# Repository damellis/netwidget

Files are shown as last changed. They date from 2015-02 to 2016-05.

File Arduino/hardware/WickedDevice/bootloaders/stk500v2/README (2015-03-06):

make clean

make goldilocks
OR
make goldilocks_22

make program

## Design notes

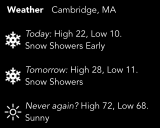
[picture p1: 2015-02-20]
Arduino/spitftbitmap/weather2.bmp

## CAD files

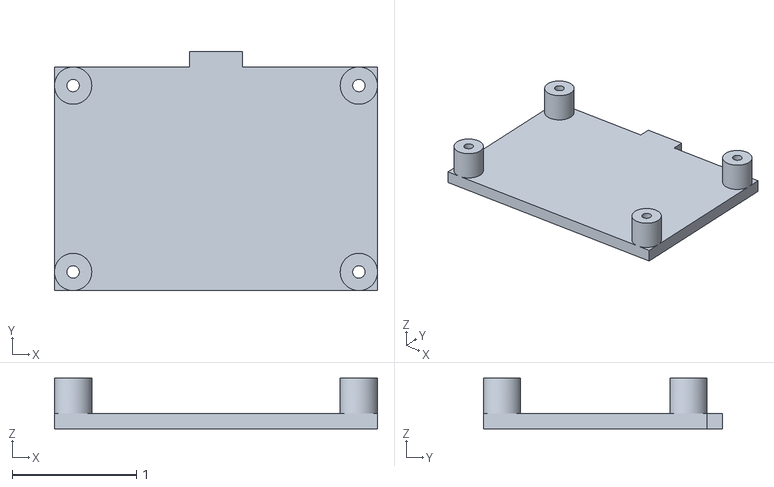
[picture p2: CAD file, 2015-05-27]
Rhino/Enclosure Bottom.stl
2.60 x 1.92 x 0.41

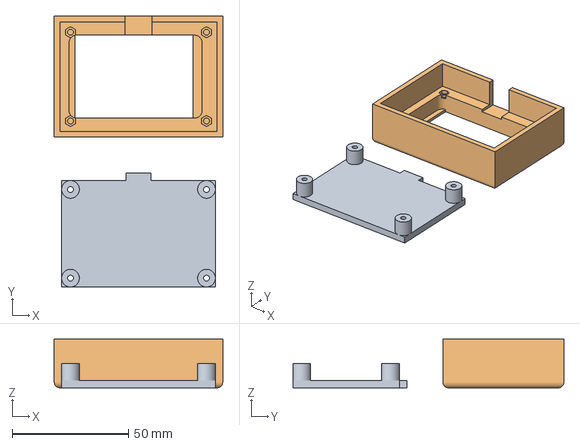
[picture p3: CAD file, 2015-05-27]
Rhino/Enclosure.amf
72.4 x 116.4 x 21.0 mm

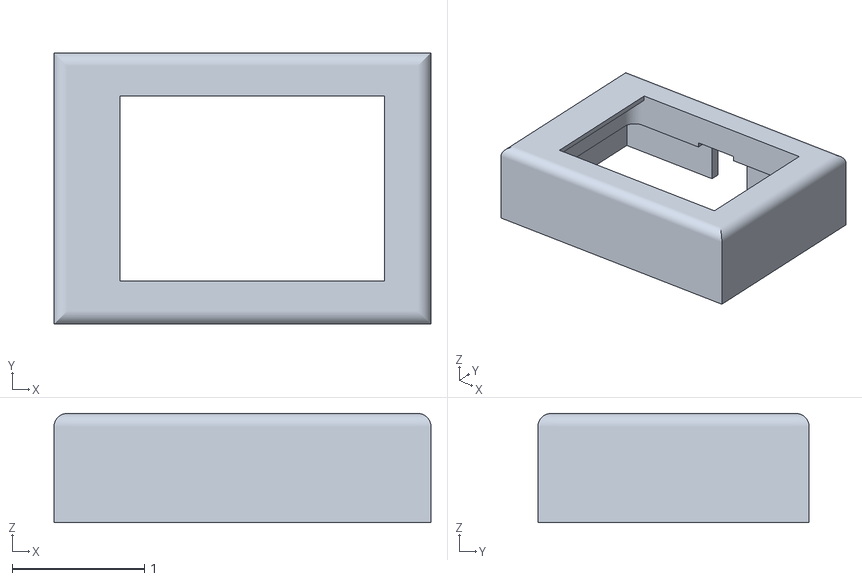
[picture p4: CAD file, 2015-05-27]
Rhino/Enclosure Top.stl
2.85 x 2.05 x 0.825

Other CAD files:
Rhino/Enclosure.3dm

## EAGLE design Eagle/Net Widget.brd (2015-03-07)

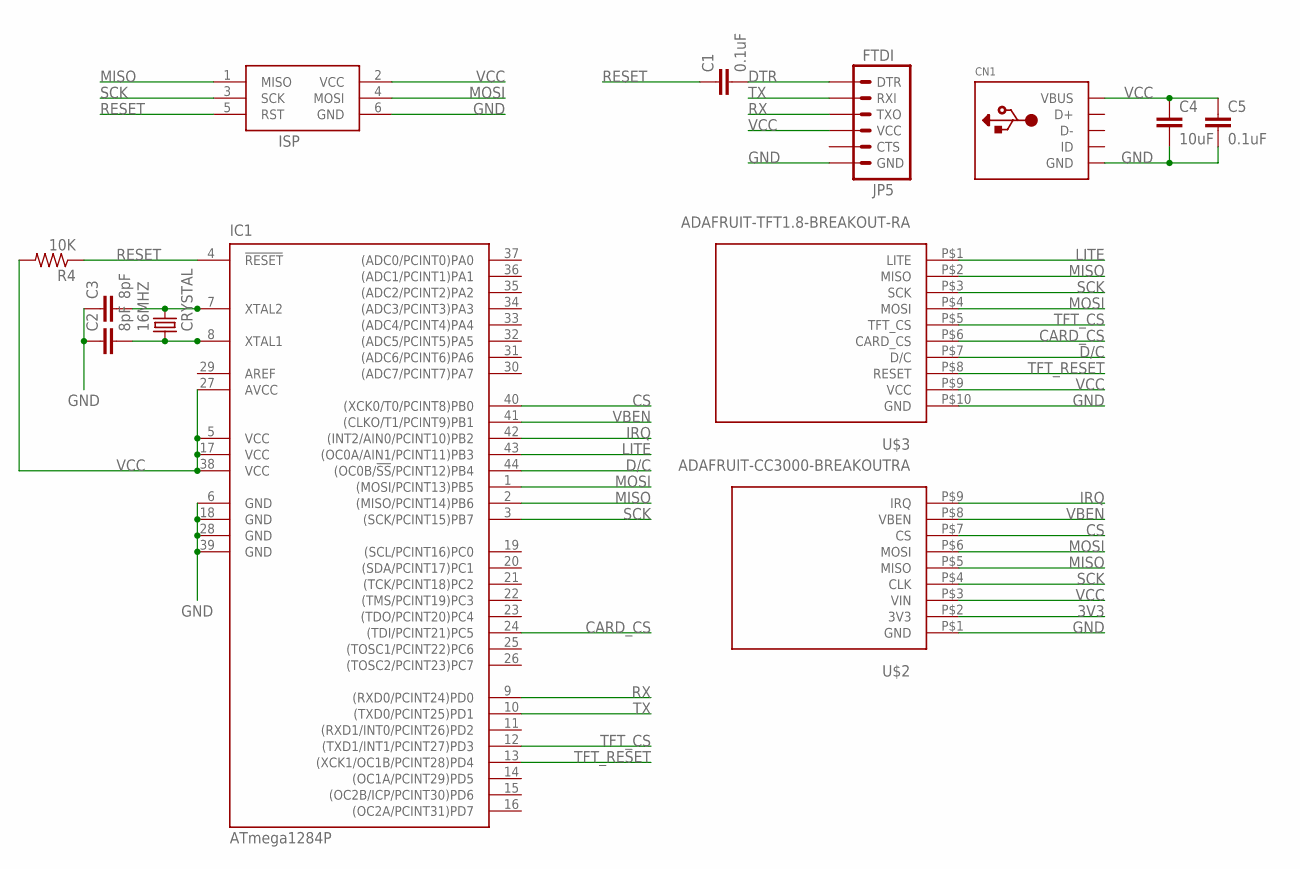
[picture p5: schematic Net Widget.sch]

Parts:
16MHZ: CRYSTAL; 2-SMD-5X3MM
C1, C5: 0.1uF; C1206
C2, C3: 8pF; C1206
C4: 10uF; C1206
CN1: USBPWR; USB-MINIB-POWER
IC1: ATmega1284P; TQFP44
ISP: AVRISP-6; AVRISP
JP5: FTDI; 1X06-SMD
R4: 10K; R1206
U$2: ADAFRUIT-CC3000-BREAKOUTRA; ADAFRUIT-CC3000-BREAKOUT-RA
U$3: ADAFRUIT-TFT1.8-BREAKOUT-RA

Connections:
3V3: U$2.P$2 (3V3)
AREF: IC1.29 (AREF)
CARD_CS: IC1.24 ((TDI/PCINT21)PC5), U$3.P$6 (CARD_CS)
CS: IC1.40 ((XCK0/T0/PCINT8)PB0), U$2.P$7 (CS)
D/C: IC1.44 ((OC0B/!SS!/PCINT12)PB4), U$3.P$7 (D/C)
DTR: C1.2, JP5.1 (DTR)
GND: C2.1, C3.1, C4.2, C5.2, CN1.GND, IC1.6 (GND), IC1.18 (GND), IC1.28 (GND), IC1.39 (GND), ISP.6 (GND), JP5.6 (GND), U$2.P$1 (GND), U$3.P$10 (GND)
IRQ: IC1.42 ((INT2/AIN0/PCINT10)PB2), U$2.P$9 (IRQ)
LITE: IC1.43 ((OC0A/AIN1/PCINT11)PB3), U$3.P$1 (LITE)
MISO: IC1.2 ((MISO/PCINT14)PB6), ISP.1 (MISO), U$2.P$5 (MISO), U$3.P$2 (MISO)
MOSI: IC1.1 ((MOSI/PCINT13)PB5), ISP.4 (MOSI), U$2.P$6 (MOSI), U$3.P$4 (MOSI)
unnamed: 16MHZ.P$2 (2), C3.2, IC1.7 (XTAL2)
unnamed: 16MHZ.P$1 (1), C2.2, IC1.8 (XTAL1)
RESET: C1.1, IC1.4 (!RESET), ISP.5 (RST), R4.1
RX: IC1.9 ((RXD0/PCINT24)PD0), JP5.3 (TXO)
SCK: IC1.3 ((SCK/PCINT15)PB7), ISP.3 (SCK), U$2.P$4 (CLK), U$3.P$3 (SCK)
TFT_CS: IC1.12 ((TXD1/INT1/PCINT27)PD3), U$3.P$5 (TFT_CS)
TFT_RESET: IC1.13 ((XCK1/OC1B/PCINT28)PD4), U$3.P$8 (RESET)
TX: IC1.10 ((TXD0/PCINT25)PD1), JP5.2 (RXI)
VBEN: IC1.41 ((CLKO/T1/PCINT9)PB1), U$2.P$8 (VBEN)
VCC: C4.1, C5.1, CN1.VBUS, IC1.5 (VCC), IC1.17 (VCC), IC1.27 (AVCC), IC1.38 (VCC), ISP.2 (VCC), JP5.4 (VCC), R4.2, U$2.P$3 (VIN), U$3.P$9 (VCC)

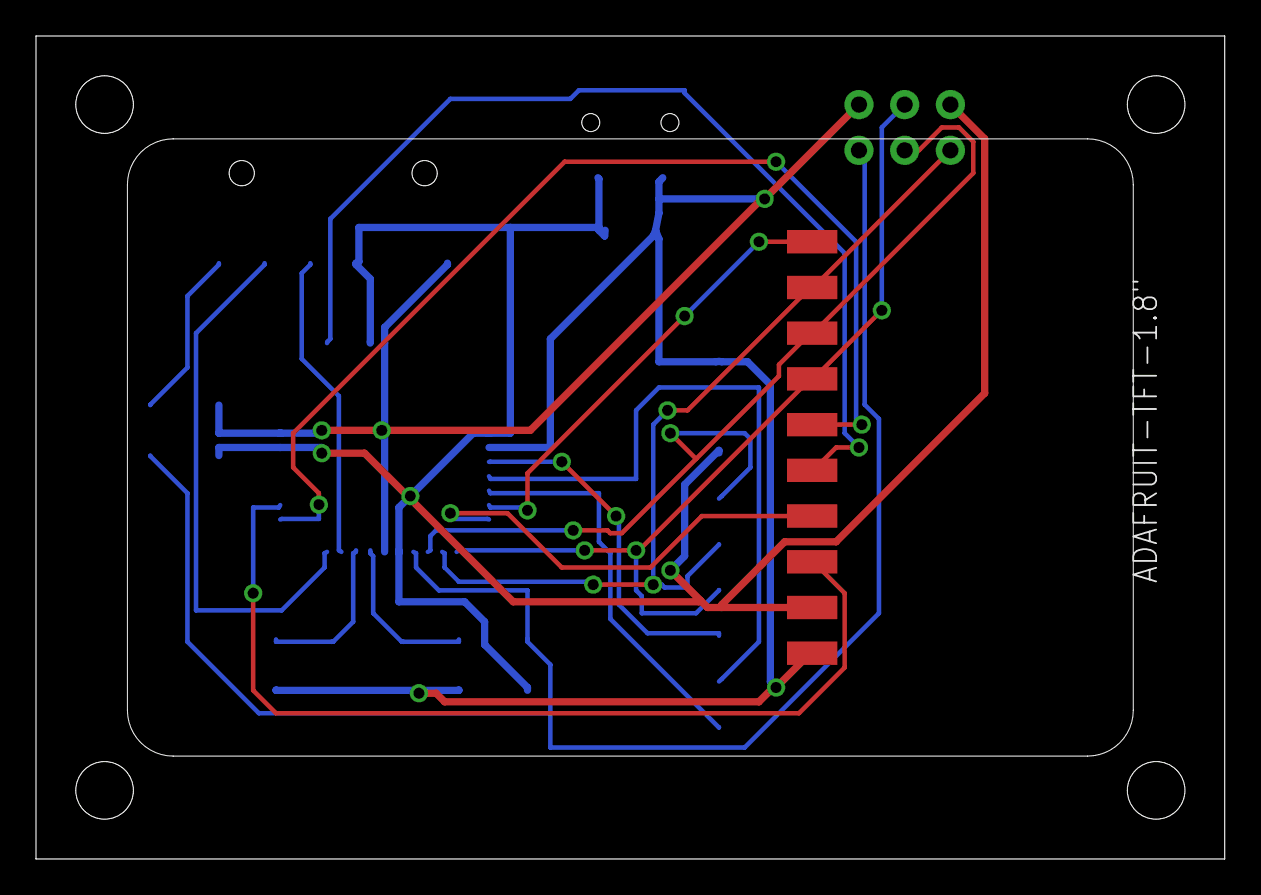
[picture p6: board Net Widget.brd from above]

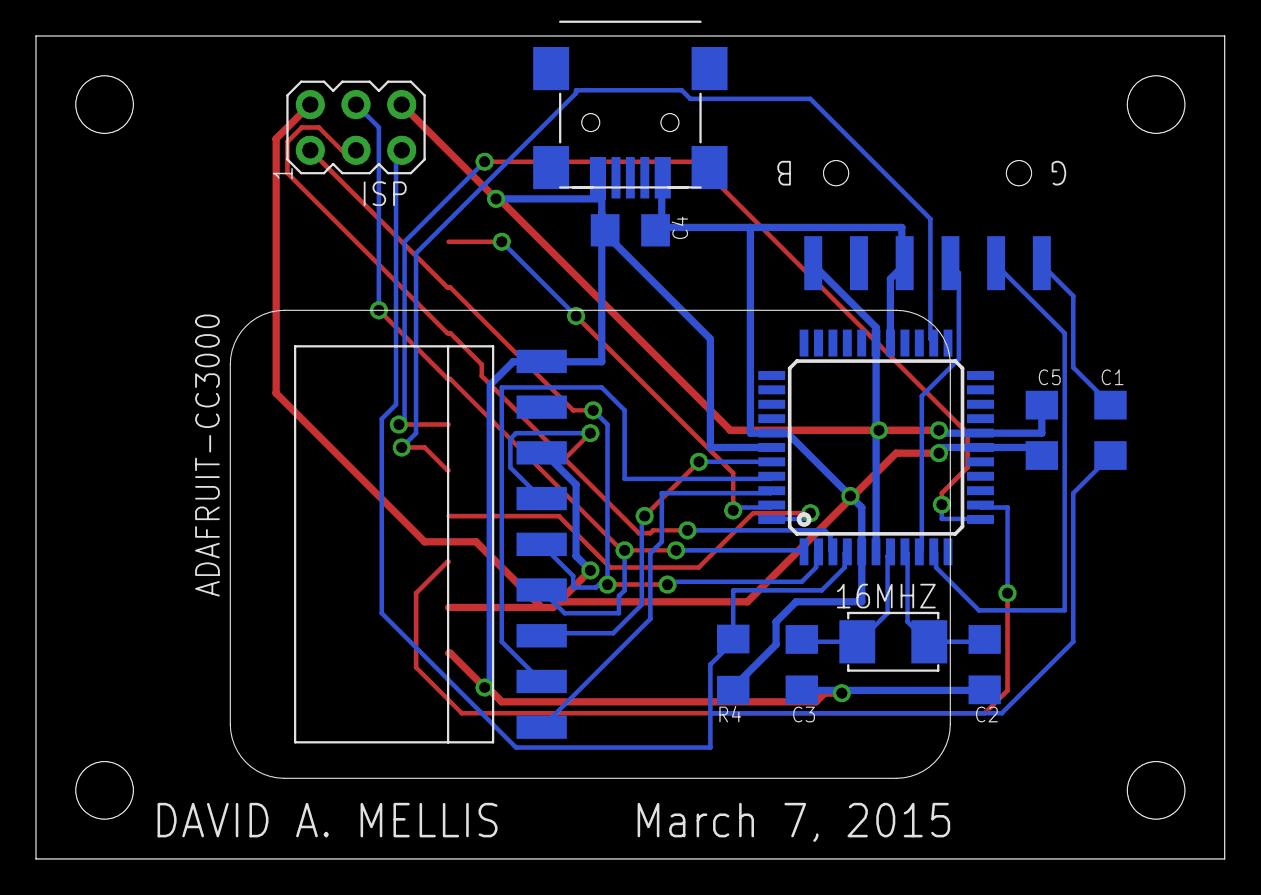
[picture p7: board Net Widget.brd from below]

Board: 2 copper layers, 66.0 x 45.7 mm, 13 parts (12 on the bottom side), 19 nets.

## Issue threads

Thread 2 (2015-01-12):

Make holes for breakout boards bigger.

damellis, 2015-01-12:

damellis, 2015-02-05:
Fixed in 80cd00d5e71479a2df2b87086648b5eec6168d64

Closed 2015-02-05.

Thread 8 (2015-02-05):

Determine correct resistor values for RGB LED.

damellis, 2015-02-05:

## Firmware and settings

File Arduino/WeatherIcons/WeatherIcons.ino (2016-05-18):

// Images from: https://thenounproject.com/DmitryBaranovskiy/collection/weatheroo/

#include <SD.h>
#include <SPI.h>
#include <Temboo.h>
#include <TFT.h>
#include <Adafruit_CC3000.h>

#include "Conditions.h"
#include "TembooAccount.h"

Adafruit_CC3000 cc3000(21, 22, 23); // CS, IRQ, VBEN
Adafruit_CC3000_Client client;
TFT tft(3, 9, 8); // CS, DC, Reset
unsigned long ip;
boolean sd;

void setup() {
  Serial.begin(9600);
  
  if(SD.begin(16)) {
    sd = true;
    for (int i = 0; i < NUM_IMAGES; i++) {
      images[i] = tft.loadImage(filenames[i]);
    }
  } else {
    sd = false;
    tft.println("SD init failed.");
    Serial.println("SD init failed.");
  }

  // TFT backlight  
  pinMode(4, OUTPUT);
  digitalWrite(4, HIGH);
  
  tft.begin();
  tft.setRotation(3);
  tft.background(0, 0, 0);
  tft.setCursor(0, 0);
  tft.stroke(255, 255, 255);
  tft.setTextWrap(true);
  
  tft.println(F("Hello."));
  Serial.println(F("Hello."));
  
  tft.println(F("Initializing CC3000..."));
  Serial.println(F("Initializing CC3000..."));

  if (!cc3000.begin()) {
    tft.println(F("cc3000.begin() failed."));
    Serial.println(F("cc3000.begin() failed."));
    while (1);
  }
  
  tft.print(F("Connecting to ")); tft.print(WIFI_SSID); tft.println(F("..."));
  Serial.print(F("Connecting to ")); Serial.print(WIFI_SSID); Serial.println(F("..."));
  
  while (!cc3000.connectToAP(WIFI_SSID, WIFI_PASS, WIFI_SEC)) {
    tft.println(F("Connection failed. Retrying in 10 seconds."));
    Serial.println(F("Connection failed. Retrying in 10 seconds."));
    delay(10000);
  }
  
  tft.print(F("Getting IP addresss..."));
  Serial.print(F("Getting IP addresss..."));
  while(!cc3000.checkDHCP()) {
    tft.print(".");
    Serial.print(".");
    delay(100);
  }
  tft.println();
  Serial.println();
  
  /* Display the IP address DNS, Gateway, etc. */  
  while (!displayConnectionDetails()) {
    delay(1000);
  }
  
  tft.println(F("Connected."));
  Serial.println(F("Connected"));
}


void loop() {
  Serial.print(F("Running GetWeatherByAddress..."));

  TembooChoreo GetWeatherByAddressChoreo(client);

  // Invoke the Temboo client
  GetWeatherByAddressChoreo.begin();

  // Set Temboo account credentials
  GetWeatherByAddressChoreo.setAccountName(TEMBOO_ACCOUNT);
  GetWeatherByAddressChoreo.setAppKeyName(TEMBOO_APP_KEY_NAME);
  GetWeatherByAddressChoreo.setAppKey(TEMBOO_APP_KEY);

  // Set Choreo inputs
  String AddressValue = "Berkeley, CA";
  GetWeatherByAddressChoreo.addInput("Address", AddressValue);
  
  // Filter Choreo output
  GetWeatherByAddressChoreo.addOutputFilter("code", "/rss/channel/item/yweather:condition/@code", "Response");  
  GetWeatherByAddressChoreo.addOutputFilter("date", "/rss/channel/item/yweather:condition/@date", "Response");
  GetWeatherByAddressChoreo.addOutputFilter("temp", "/rss/channel/item/yweather:condition/@temp", "Response");
  GetWeatherByAddressChoreo.addOutputFilter("text", "/rss/channel/item/yweather:condition/@text", "Response");
  GetWeatherByAddressChoreo.addOutputFilter("date1", "/rss/channel/item/yweather:forecast[1]/@date", "Response");
  GetWeatherByAddressChoreo.addOutputFilter("low1", "/rss/channel/item/yweather:forecast[1]/@low", "Response");
  GetWeatherByAddressChoreo.addOutputFilter("high1", "/rss/channel/item/yweather:forecast[1]/@high", "Response");
  GetWeatherByAddressChoreo.addOutputFilter("text1", "/rss/channel/item/yweather:forecast[1]/@text", "Response");
  GetWeatherByAddressChoreo.addOutputFilter("date2", "/rss/channel/item/yweather:forecast[2]/@date", "Response");
  GetWeatherByAddressChoreo.addOutputFilter("low2", "/rss/channel/item/yweather:forecast[2]/@low", "Response");
  GetWeatherByAddressChoreo.addOutputFilter("high2", "/rss/channel/item/yweather:forecast[2]/@high", "Response");
  GetWeatherByAddressChoreo.addOutputFilter("text2", "/rss/channel/item/yweather:forecast[2]/@text", "Response");

  // Identify the Choreo to run
  GetWeatherByAddressChoreo.setChoreo("/Library/Yahoo/Weather/GetWeatherByAddress");
  
  // Run the Choreo; when results are available, print them to serial
  GetWeatherByAddressChoreo.run();
  
  Serial.println("done.");
  
  String date, temp, text, date1, low1, high1, text1, date2, low2, high2, text2, http_code;
  int code;
  
  Serial.println(F("Retrieving results..."));

  while (GetWeatherByAddressChoreo.available()) {
    String key = GetWeatherByAddressChoreo.readStringUntil('\x1F');
    String value = GetWeatherByAddressChoreo.readStringUntil('\x1E');
    
    key.trim(); value.trim();
    
    Serial.print(key);
    Serial.print("\t");
    Serial.print(value);
    Serial.println();
    
    if (key == "code") code = value.toInt();
    if (key == "date") date = value;
    if (key == "temp") temp = value;
    if (key == "text") text = value;
    if (key == "date1") date1 = value;
    if (key == "low1") low1 = value;
    if (key == "high1") high1 = value;
    if (key == "text1") text1 = value;
    if (key == "date2") date2 = value;
    if (key == "low2") low2 = value;
    if (key == "high2") high2 = value;
    if (key == "text2") text2 = value;
    if (key == "HTTP_CODE") http_code = value;
  }
  GetWeatherByAddressChoreo.close();

  // if successful, print the new forecast.
  if (http_code.equals("200")) {
    Serial.println("Success!");
    tft.background(0, 0, 0); // clear screen
    tft.setCursor(0, 0);
    tft.stroke(255, 255, 255);
    tft.setTextWrap(true);
    tft.setTextSize(3);
    tft.println(temp);
    tft.setTextSize(1);
    tft.println(text);
    tft.println();
    tft.println();
    tft.print("Today: "); tft.print(low1); tft.print("-"); tft.print(high1); tft.print(" F"); tft.println();
    tft.println(text1);
    tft.println();
    tft.print("Tomorrow: "); tft.print(low2); tft.print("-"); tft.print(high2); tft.print(" F"); tft.println();
    tft.println(text2);
    tft.setCursor(0, 108);
    tft.println(AddressValue);
    tft.println(date.substring(0, date.lastIndexOf(" "))); // remove timezone
    if (sd && conditions[code] != -1) tft.image(images[conditions[code]], 110, 0);
    Serial.println("Done.");
    delay(1L * 60 * 60 * 1000); // on success, wait one hour
  } else {
//    tft.setCursor(0, 100);
//    tft.print(http_code);
    delay(30L * 1000); // otherwise, wait 30 seconds
  }
}

bool displayConnectionDetails(void)
{
  uint32_t ipAddress, netmask, gateway, dhcpserv, dnsserv;
  
  if(!cc3000.getIPAddress(&ipAddress, &netmask, &gateway, &dhcpserv, &dnsserv))
  {
    Serial.println(F("Unable to retrieve the IP Address!\r\n"));
    return false;
  }
  else
  {
    Serial.print(F("\nIP Addr: ")); cc3000.printIPdotsRev(ipAddress);
    Serial.print(F("\nNetmask: ")); cc3000.printIPdotsRev(netmask);
    Serial.print(F("\nGateway: ")); cc3000.printIPdotsRev(gateway);
    Serial.print(F("\nDHCPsrv: ")); cc3000.printIPdotsRev(dhcpserv);
    Serial.print(F("\nDNSserv: ")); cc3000.printIPdotsRev(dnsserv);
    Serial.println();
    return true;
  }
}

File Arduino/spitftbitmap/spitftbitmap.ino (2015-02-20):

/***************************************************
  This is a library for the Adafruit 1.8" SPI display.

This library works with the Adafruit 1.8" TFT Breakout w/SD card
  ----> http://www.adafruit.com/products/358
The 1.8" TFT shield
  ----> https://www.adafruit.com/product/802
The 1.44" TFT breakout
  ----> https://www.adafruit.com/product/2088
as well as Adafruit raw 1.8" TFT display
  ----> http://www.adafruit.com/products/618

  Check out the links above for our tutorials and wiring diagrams
  These displays use SPI to communicate, 4 or 5 pins are required to
  interface (RST is optional)
  Adafruit invests time and resources providing this open source code,
  please support Adafruit and open-source hardware by purchasing
  products from Adafruit!

  Written by Limor Fried/Ladyada for Adafruit Industries.
  MIT license, all text above must be included in any redistribution
 ****************************************************/

#include <Adafruit_GFX.h>    // Core graphics library
#include <Adafruit_ST7735.h> // Hardware-specific library
#include <SPI.h>
#include <SD.h>

// TFT display and SD card will share the hardware SPI interface.
// Hardware SPI pins are specific to the Arduino board type and
// cannot be remapped to alternate pins.  For Arduino Uno,
// Duemilanove, etc., pin 11 = MOSI, pin 12 = MISO, pin 13 = SCK.
#define TFT_CS   0  // Chip select line for TFT display
#define TFT_RST  1  // Reset line for TFT (or see below...)
#define TFT_DC   4  // Data/command line for TFT

#define SD_CS   18  // Chip select line for SD card

//Use this reset pin for the shield!
//#define TFT_RST  0  // you can also connect this to the Arduino reset!

Adafruit_ST7735 tft = Adafruit_ST7735(TFT_CS, TFT_DC, TFT_RST);

void setup(void) {
  Serial.begin(9600);

  // TFT backlight  
  pinMode(3, OUTPUT);
  digitalWrite(3, HIGH);

  // Use this initializer if you're using a 1.8" TFT
  tft.initR(INITR_BLACKTAB);

  // Use this initializer (uncomment) if you're using a 1.44" TFT
  //tft.initR(INITR_144GREENTAB);
  
  tft.setRotation(3);

  Serial.print("Initializing SD card...");
  if (!SD.begin(SD_CS)) {
    Serial.println("failed!");
    return;
  }
  Serial.println("OK!");

  // change the name here!
  bmpDraw("weather2.bmp", 0, 0);
  // wait 5 seconds
  delay(5000);
}

void loop() {
// uncomment these lines to draw bitmaps in different locations/rotations!
/*
  tft.fillScreen(ST7735_BLACK); // Clear display
  for(uint8_t i=0; i<4; i++)    // Draw 4 parrots
    bmpDraw("parrot.bmp", tft.width() / 4 * i, tft.height() / 4 * i);
  delay(1000);
  tft.setRotation(tft.getRotation() + 1); // Inc rotation 90 degrees
*/
}

// This function opens a Windows Bitmap (BMP) file and
// displays it at the given coordinates.  It's sped up
// by reading many pixels worth of data at a time
// (rather than pixel by pixel).  Increasing the buffer
// size takes more of the Arduino's precious RAM but
// makes loading a little faster.  20 pixels seems a
// good balance.

#define BUFFPIXEL 20

void bmpDraw(char *filename, uint8_t x, uint8_t y) {

  File     bmpFile;
  int      bmpWidth, bmpHeight;   // W+H in pixels
  uint8_t  bmpDepth;              // Bit depth (currently must be 24)
  uint32_t bmpImageoffset;        // Start of image data in file
  uint32_t rowSize;               // Not always = bmpWidth; may have padding
  uint8_t  sdbuffer[3*BUFFPIXEL]; // pixel buffer (R+G+B per pixel)
  uint8_t  buffidx = sizeof(sdbuffer); // Current position in sdbuffer
  boolean  goodBmp = false;       // Set to true on valid header parse
  boolean  flip    = true;        // BMP is stored bottom-to-top
  int      w, h, row, col;
  uint8_t  r, g, b;
  uint32_t pos = 0, startTime = millis();

  if((x >= tft.width()) || (y >= tft.height())) return;

  Serial.println();
  Serial.print("Loading image '");
  Serial.print(filename);
  Serial.println('\'');

  // Open requested file on SD card
  if ((bmpFile = SD.open(filename)) == NULL) {
    Serial.print("File not found");
    return;
  }

  // Parse BMP header
  if(read16(bmpFile) == 0x4D42) { // BMP signature
    Serial.print("File size: "); Serial.println(read32(bmpFile));
    (void)read32(bmpFile); // Read & ignore creator bytes
    bmpImageoffset = read32(bmpFile); // Start of image data
    Serial.print("Image Offset: "); Serial.println(bmpImageoffset, DEC);
    // Read DIB header
    Serial.print("Header size: "); Serial.println(read32(bmpFile));
    bmpWidth  = read32(bmpFile);
    bmpHeight = read32(bmpFile);
    if(read16(bmpFile) == 1) { // # planes -- must be '1'
      bmpDepth = read16(bmpFile); // bits per pixel
      Serial.print("Bit Depth: "); Serial.println(bmpDepth);
      if((bmpDepth == 24) && (read32(bmpFile) == 0)) { // 0 = uncompressed

        goodBmp = true; // Supported BMP format -- proceed!
        Serial.print("Image size: ");
        Serial.print(bmpWidth);
        Serial.print('x');
        Serial.println(bmpHeight);

        // BMP rows are padded (if needed) to 4-byte boundary
        rowSize = (bmpWidth * 3 + 3) & ~3;

        // If bmpHeight is negative, image is in top-down order.
        // This is not canon but has been observed in the wild.
        if(bmpHeight < 0) {
          bmpHeight = -bmpHeight;
          flip      = false;
        }

        // Crop area to be loaded
        w = bmpWidth;
        h = bmpHeight;
        if((x+w-1) >= tft.width())  w = tft.width()  - x;
        if((y+h-1) >= tft.height()) h = tft.height() - y;

        // Set TFT address window to clipped image bounds
        tft.setAddrWindow(x, y, x+w-1, y+h-1);

        for (row=0; row<h; row++) { // For each scanline...

          // Seek to start of scan line.  It might seem labor-
          // intensive to be doing this on every line, but this
          // method covers a lot of gritty details like cropping
          // and scanline padding.  Also, the seek only takes
          // place if the file position actually needs to change
          // (avoids a lot of cluster math in SD library).
          if(flip) // Bitmap is stored bottom-to-top order (normal BMP)
            pos = bmpImageoffset + (bmpHeight - 1 - row) * rowSize;
          else     // Bitmap is stored top-to-bottom
            pos = bmpImageoffset + row * rowSize;
          if(bmpFile.position() != pos) { // Need seek?
            bmpFile.seek(pos);
            buffidx = sizeof(sdbuffer); // Force buffer reload
          }

          for (col=0; col<w; col++) { // For each pixel...
            // Time to read more pixel data?
            if (buffidx >= sizeof(sdbuffer)) { // Indeed
              bmpFile.read(sdbuffer, sizeof(sdbuffer));
              buffidx = 0; // Set index to beginning
            }
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

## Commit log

2015-01-12 Initial commit.
    [Net Widget.brd, Net Widget.sch]
2015-01-19 Move Eagle files to sub-directory.
    [Net Widget.brd, Net Widget.sch]
2015-01-19 Add Adafruit's CC3000, GFX, and ST7735 libraries for Arduino.
2015-01-19 Switch to Net Widget.lbr and increase hole sizes.
    [Net Widget.brd, Net Widget.sch]
2015-01-19 Replace ATmega32U4 w/ ATmega1284P.
    Initial pass. Adds an FTDI header and replaces the Mini-USB footprint.
    [Net Widget.brd, Net Widget.sch]
2015-01-20 Clean up library and board.
    Add breakout headers, move components into Net Widget library, switch
    to Mini USB B connector with holes for mounting posts, silk screen
    layout, etc.
    [Net Widget.brd, Net Widget.sch]
2015-01-20 Arduino test sketch for TFT display.
2015-01-20 Generate gerbers.
2015-01-23 Add board definition. Update example pin numbers.
2015-01-26 Adjust pin numbers for ATmega1284 board.
2015-02-12 Acrylic enclosure.
    [Net Widget.brd]
2015-02-12 SMD pads for breakout boards and layout.
    Moved a bunch of things around after switching to right-angle
    surface-mount headers for the CC3000 and TFT breakout boards.
    [Net Widget.brd, Net Widget.sch]
2015-02-12 Remove broken-out pins.
    [Net Widget.brd, Net Widget.sch]
2015-02-19 Add SPI transactions to ST7735 TFT library.
    Otherwise, the CC3000 seems to interfere with communication to the
    display.
2015-02-20 Move CC3000, re-route, silk screen cleanup.
    [Net Widget.brd, Net Widget.sch]
2015-03-06 Tempo weather Arduino sketch for this PCB.
2015-03-06 Update pins for WildFire board definition.
2015-03-06 Update pins for WildFire mapping and this PCB.
2015-03-07 Match pin numbers to WildFire; route.
    [Net Widget.brd, Net Widget.sch]
2015-03-07 Update pins for WildFire / new PCB.
2015-03-14 Update pins for new PCB.
2015-05-27 3D-printed enclosure.
    [Enclosure Bottom.stl, Enclosure Top.stl, Enclosure.3dm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]

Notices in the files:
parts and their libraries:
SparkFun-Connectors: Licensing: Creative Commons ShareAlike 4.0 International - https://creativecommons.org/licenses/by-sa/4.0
